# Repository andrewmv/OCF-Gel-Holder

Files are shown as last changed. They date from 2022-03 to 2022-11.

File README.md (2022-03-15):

# Parametric Profoto OCF II Magnetic Gel Clamps

## And OCF I to OCF II Gel Adapter

These gel-retainer rings have cavities for print-in magnets that line up with the magnets in Profoto's official OCF II stackable gel and grid accessories, so you can use arbitrary gels with your Profoto strobe heads without having to use an OCF II Gel Ring adapter, and without cutting your gels.

You can use these to attach a single gel with no other modifiers, multiple gels, or combine it with official OCF II gels and grids.

Also allows you use your existing OCF I gels without cutting or modifying them.

## Customizing And Printing

I recommend using a heat-tolerant material such as ABS.

I used 4x2 mm disc magnets, stacked in pairs - a total of 24 magnets for the rings, and 48 for the riser. I recommend using rare earth neodynium magnets if you're planning on having additional accessories stacked on top of these.

I sourced them from:  https://www.apexmagnets.com/magnets/4mm-x-2mm-disc-neodymium-magnets

If you have a different size of magnet, or don't want to stack them, you can change `mag_dia` and `mag_depth` accordingly, though anything greater than 4mm in diameter will require thicker walls.

Configure your slicer to pause the job at the appropriate layers to print the magnets in, or change the `mag_bury` parameter to 0 to leave the magnet cavities exposed so you can glue them in after printing.

You can set `test_fit=true` in the clamp to print a small test part to ensure your magnets fit correctly.

## Use

To use these, you'll still need one of Profoto's OCF II magnetic mounting adapters - either the "OCF II Gel & Grid Holder" or "OCF II Barndoor" - though I've only tested fit with the former.

Clamp your gels between two of these rings, or between one ring and an official accessory like a magnetic grid.

Use the riser to attach larger gels that won't fit inside the speedring adapter built into the Profoto Gel Adapter. If you're using at least two official OCF II gels or grids, they'll be deep enough that you won't need the riser.

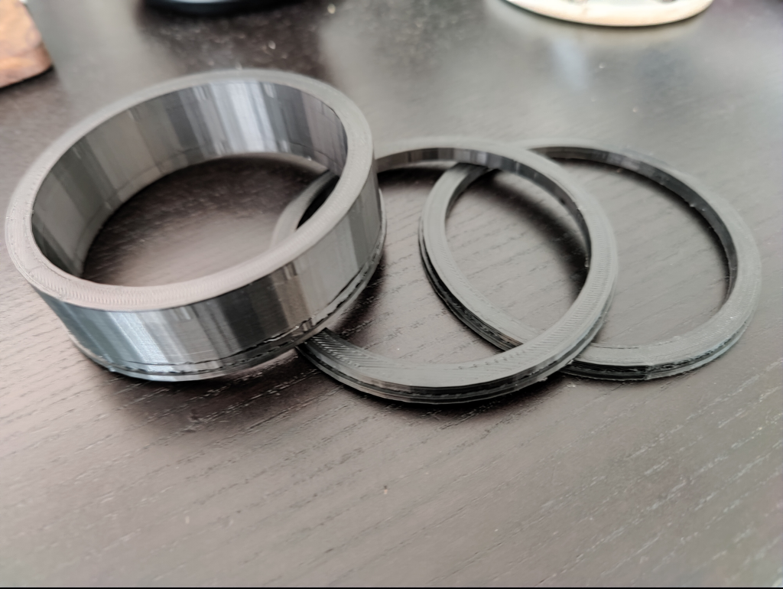
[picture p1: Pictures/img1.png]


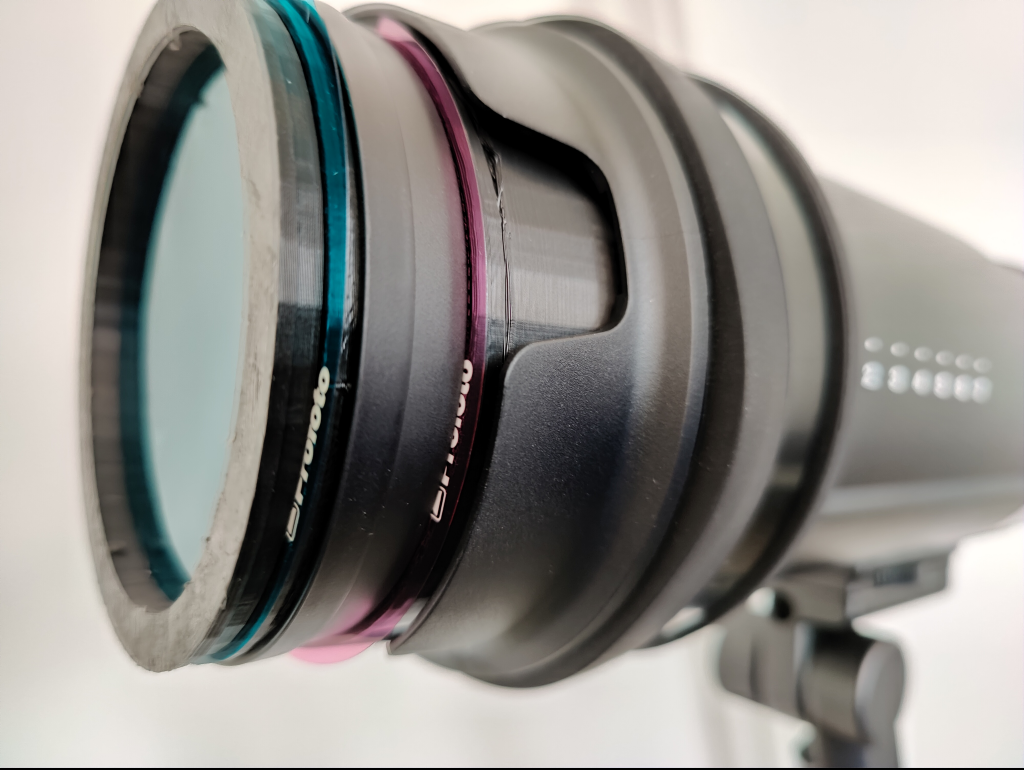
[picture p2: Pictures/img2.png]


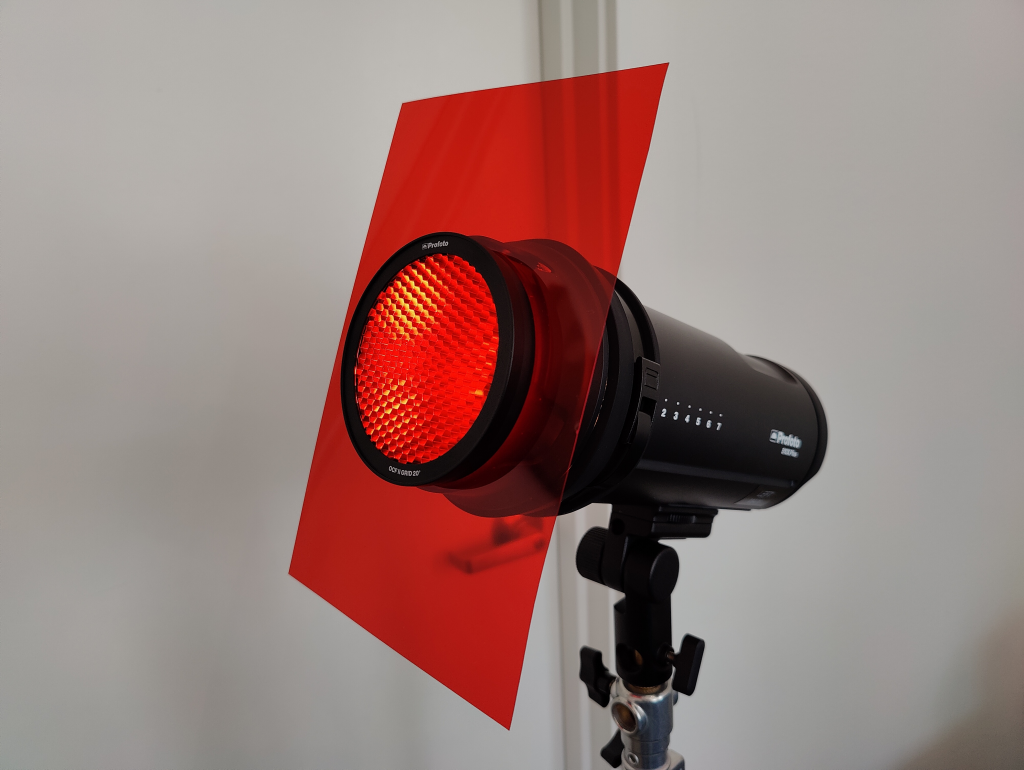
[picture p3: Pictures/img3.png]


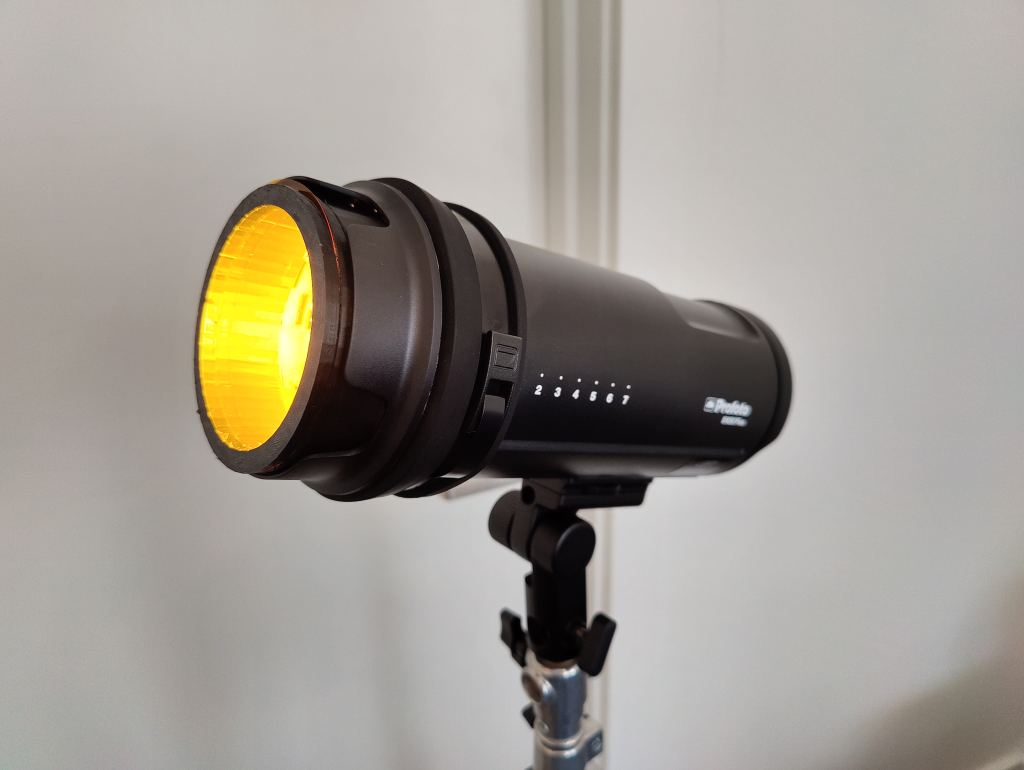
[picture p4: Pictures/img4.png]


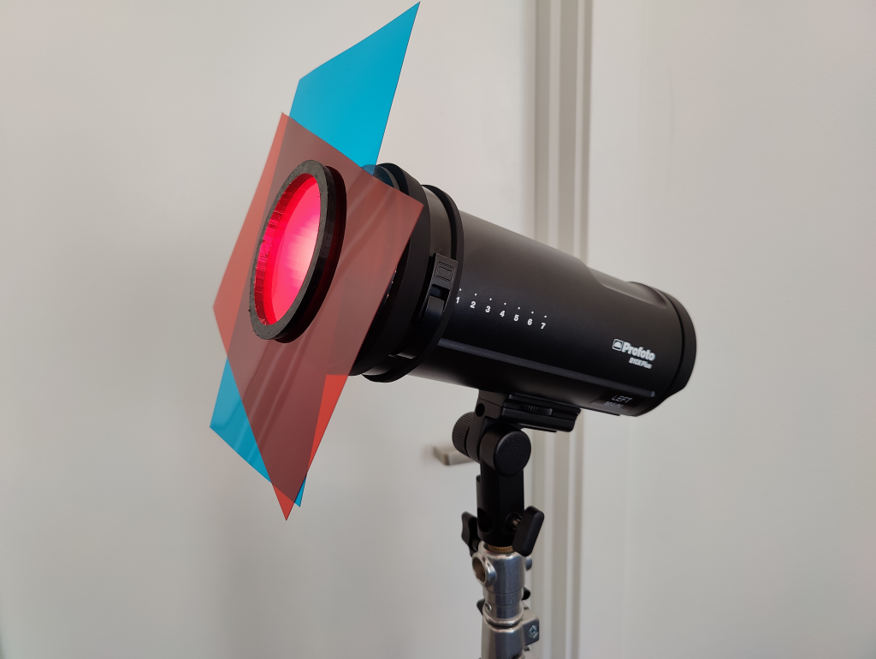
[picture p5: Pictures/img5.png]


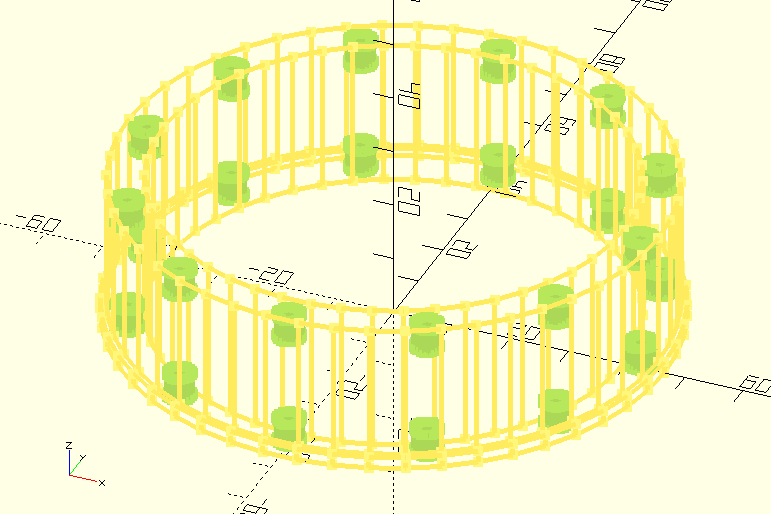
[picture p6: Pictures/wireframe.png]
wireframe


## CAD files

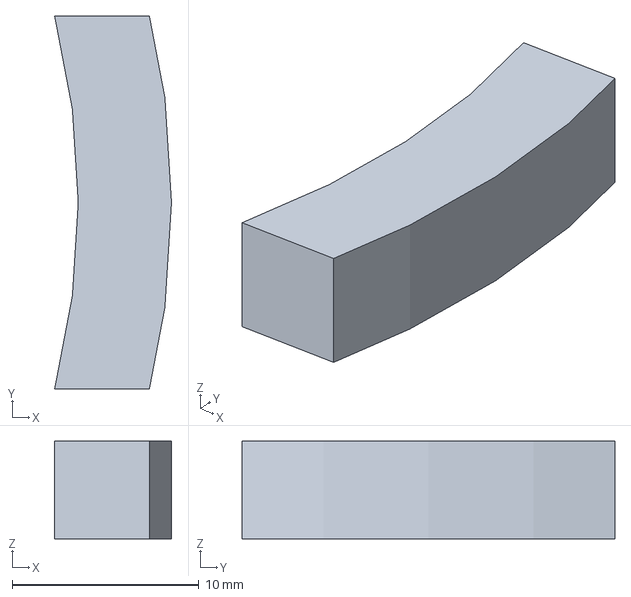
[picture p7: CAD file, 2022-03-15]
MSMV2E3D_ocf-gel-testfit.3mf
6.27 x 20.0 x 5.25 mm

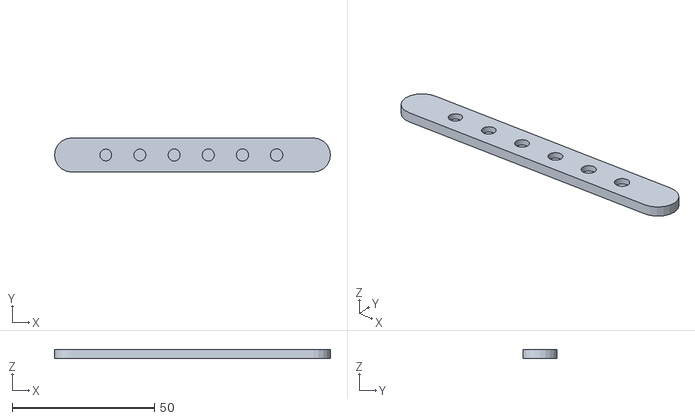
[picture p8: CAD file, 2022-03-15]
test-fit.stl
96.9 x 12.0 x 3.00

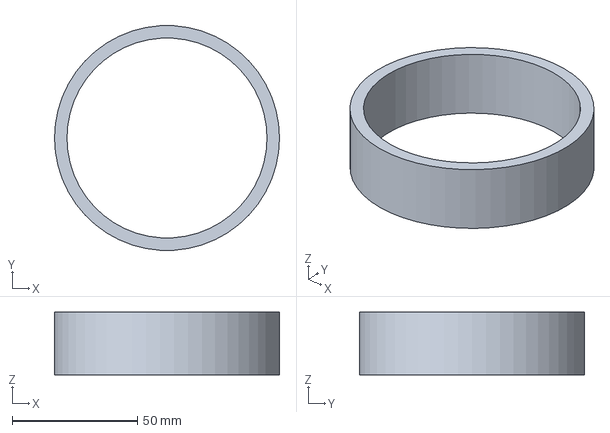
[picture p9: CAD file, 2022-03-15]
MSMV2E3D_ocf-gel-riser.3mf
90.0 x 89.8 x 25.0 mm

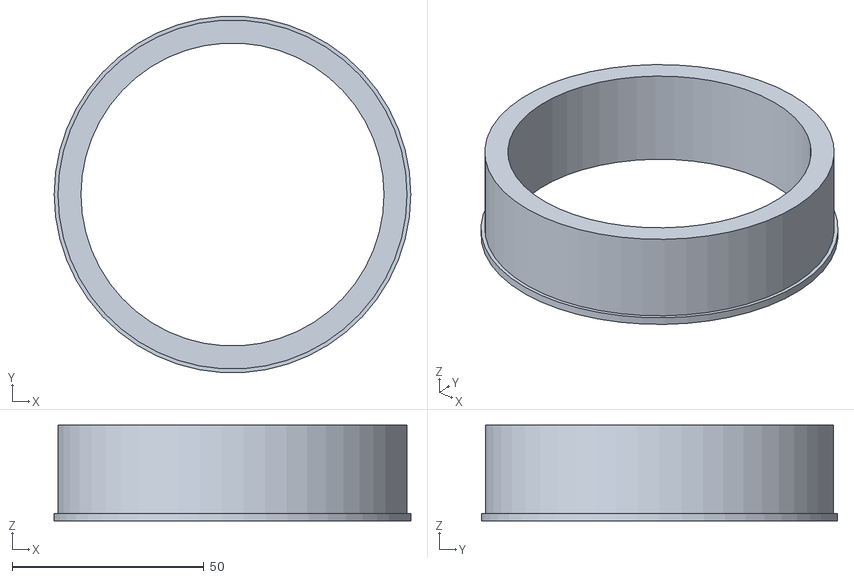
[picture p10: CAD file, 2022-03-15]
ocf-gel-riser.stl
93.0 x 92.8 x 25.0

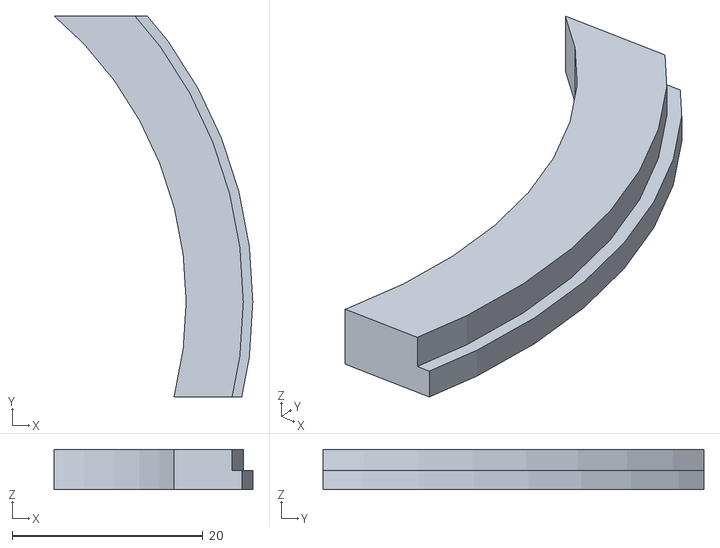
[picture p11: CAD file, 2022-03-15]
ocf-gel-testfit.stl
20.9 x 40.0 x 4.25

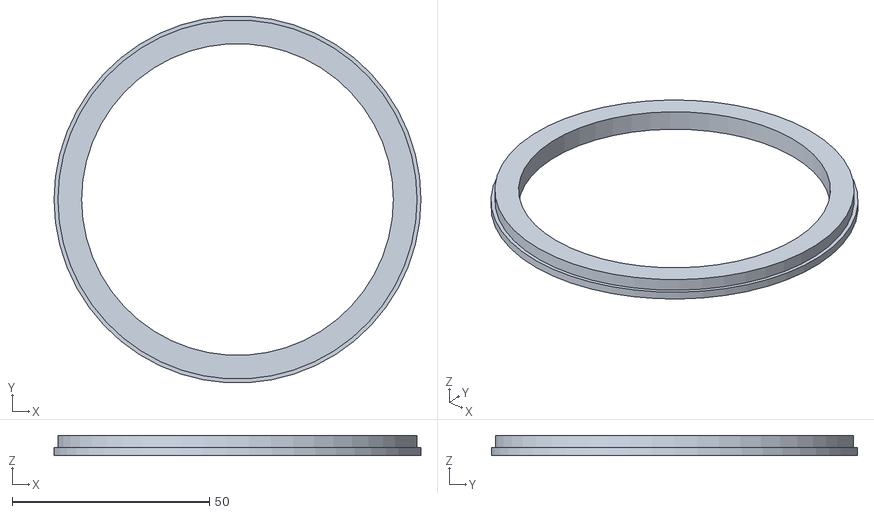
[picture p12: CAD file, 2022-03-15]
ocf-gel-clamp.stl
93.0 x 92.8 x 5.10

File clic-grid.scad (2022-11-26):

include <ocf-gel-modules.scad>
include <Hexes.scad>

//// USER VARIABLES ////
//// All values in mm ////

outer_dia = 70; // Outer Diameter
inner_dia = 60; // Inner Diameter
grid_depth = 13;
depth = grid_depth + 3;     // Total depth (height) of ring
$fn = 50;       // Polygon count of circles

nozzle_width = 0.5;
grid_angle = 20; // Degrees

mag_dia = 4.40;   // Diameter dimension of magnets
mag_depth = 2.2;  // Depth (height) dimenstion of magnets
mag_bury = -0.1;	  // How deep to bury the magnets in the part
mag_count = 12;   // Number of magnets around circumference of ring
//mag_tol = 0.25; // Tolerace of magnet inserts (added to size of inserts)

lip_w = 2;  // Width of handle/lip for removal
lip_h = 2;  // Height of lip

//// COMPUTED VARIABLES - You shouldn't need to touch these ////

hex_r = (grid_depth * tan(grid_angle)) / 2;
mag_hole_depth = mag_depth + mag_bury;
mag_degrees = 360 / mag_count;
ring_center = (inner_dia + ((outer_dia - inner_dia) / 2)) / 2;

//// ASSEMBLY - Now render the part with these values ////

asm();

intersection() {
    translate([-inner_dia/2,-inner_dia/2,0])
        bounded_hex_lattice(size=[inner_dia,inner_dia,grid_depth], r=hex_r, spacing=nozzle_width, border=0);
    cylinder(h=depth, r=inner_dia/2);
}

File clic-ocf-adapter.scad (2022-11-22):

//// USER VARIABLES ////
//// All values in mm ////

// OCF (Bigger) ring
ocf_outer_dia = 91; // Outer Diameter
ocf_inner_dia = 79; // Inner Diameter

// Clic (Smaller) ring
clic_outer_dia = 70; // Outer Diameter
clic_inner_dia = 60; // Inner Diameter

depth = 15;     // Total depth (height) of ring
ring_depth = 5;
$fn = 50;       // Polygon count of circles

mag_dia = 4.15;    // Diameter dimension of magnets
mag_depth = 2.0;  // Depth (height) dimenstion of magnets
mag_bury = -0.1; // How deep to bury the magnets in the part
ocf_mag_count = 12; // Number of magnets around circumference of OCF ring
clic_mag_count = 12; // Number of magnets around circumference of Clic ring
//mag_tol = 0.25; // Tolerace of magnet inserts (added to size of inserts)

lip_w = 2;  // Width of handle/lip for removal
lip_h = 2;  // Height of lip

//// COMPUTED VARIABLES - You shouldn't need to touch these ////

mag_hole_depth = mag_depth + mag_bury;
// ocf_ring_center = (ocf_inner_dia) + ((ocf_outer_dia - ocf_inner_dia) / 4);
ocf_ring_center = ((ocf_outer_dia / 2) + (ocf_inner_dia / 2)) / 2;
// clic_ring_center = (clic_inner_dia) + ((clic_outer_dia - clic_inner_dia) / 4);
clic_ring_center = ((clic_outer_dia / 2) + (clic_inner_dia / 2)) / 2;

//// MODULES

// Wrapper for magnet inserts
module mag_rings() {
    //clic magnet ring (closest to build plate)
    mag_inserts(mag_bury, clic_ring_center, clic_mag_count);
    //ocf magnet ring (furthest from build plate)
    mag_inserts(depth + (2 * ring_depth) - mag_hole_depth - mag_bury, ocf_ring_center, ocf_mag_count);
}

// Subtractive circular array of magnet inserts
module mag_inserts(zpos, ring_center, mag_count) {
	mag_degrees = 360 / mag_count;
    for (i = [0:1:mag_count]) {
        rotate([0,0,mag_degrees * i]) {
            translate([ring_center,0,zpos]) {
                linear_extrude(mag_depth) {
                    circle(r=(mag_dia / 2), $fn=20);
                }
            }
        }
    }
}

// Define the parameters for the cross-sectional polygon
a = (clic_outer_dia / 2) - (clic_inner_dia / 2);
b = ring_depth;
c = depth;
d = (ocf_inner_dia / 2) - (clic_inner_dia / 2);
e = (ocf_outer_dia / 2) - (ocf_inner_dia / 2);
points = [
	[0,0],
	[0,b],
	[d,b+c],
	[d,b+c+b],
	[d+e,b+c+b],
	[d+e,b+c],
	[a,b],
	[a,0]	
];

//// ASSEMBLY - Now render the part with these values ////

difference() {
	rotate_extrude(angle=360, convexity=2) {
		translate([clic_inner_dia / 2,0,0])
			polygon(points=points);
	}

	color("red")	mag_rings();
}

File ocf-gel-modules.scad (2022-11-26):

// Assembly
module asm() {
    difference() {
        union() {
            ring();
            lip();
        }
        color("red") mag_rings();
    }
}

// Main body of part
module ring() {
    linear_extrude(depth) {
        difference() {
            circle(r=(outer_dia / 2));
            circle(r=(inner_dia / 2));
        }
    }
}

// Wider lip at the top for easier removal
module lip() {
    linear_extrude(lip_h) {
        difference() {
            circle(r=(outer_dia + lip_w) / 2);
            circle(r=(inner_dia / 2));
        }
    }
}

// Wrapper for magnet inserts
module mag_rings() {
    //top magnet ring (closest to build plate)
    mag_inserts(mag_bury, mag_dia + 0.25); // Allow extra slop for the buildplate layer
    // bottom magnet ring (furthest from build plate)
    if (depth > 10) {
        mag_inserts(depth - mag_hole_depth, mag_dia);
    }
}

// Subtractive circular array of magnet inserts
module mag_inserts(zpos, d) {
    for (i = [0:1:mag_count]) {
        rotate([0,0,mag_degrees * i]) {
            translate([ring_center,0,zpos]) {
                linear_extrude(mag_depth) {
                    circle(r=(d / 2), $fn=20);
                }
            }
        }
    }
}

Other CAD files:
ocf-gel-clamp.scad
ocf-gel-riser.scad
ocf-grid.scad
test-fit.scad

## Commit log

2022-11-22 Added grid, clic adapter, gitignore
    [clic-ocf-adapter.scad, ocf-gel-modules.scad, ocf-grid.scad]
2022-11-26 Added grids, tuned magnet diameter
    [clic-grid.scad, ocf-gel-clamp.scad, ocf-gel-modules.scad]
